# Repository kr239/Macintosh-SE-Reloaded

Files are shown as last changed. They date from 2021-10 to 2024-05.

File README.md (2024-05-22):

# Macintosh SE Reloaded

Finished Logic Board
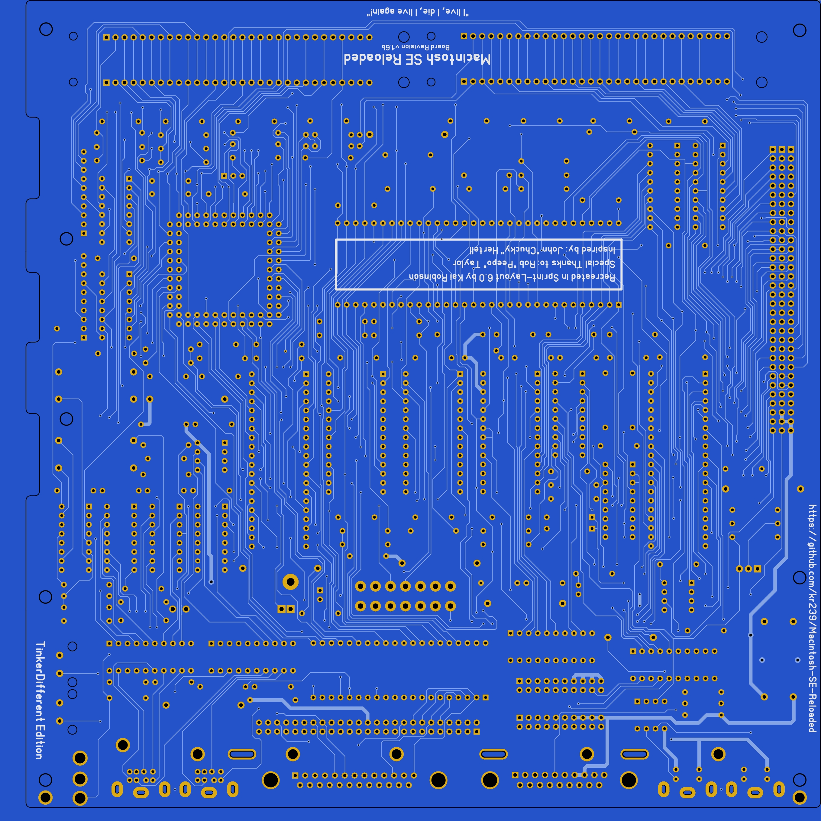
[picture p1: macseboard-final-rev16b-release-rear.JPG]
Finished Logic Board - Bottom


**Latest version, v1.6 adds an A17 address pin next to **U2E**, a 74F257 to allow for potential ROM upgrades as the standard ROM sockets only allow A0 to A16 address lines.**

So many classic macs, starting with the SE, have died because of Apple's short sighted decision to add a battery to the board. This inevitably leaks and causes a horrific amount of damage. Luckily - most of the custom chips survive even this, so I decided to make a near 1:1 reproduction of the board, using Sprint Layout v6.0

Project inspired by Rob 'Peepo' Taylors work on the A500++ and the SixtyClone PCB's, which in turn were inspired by John 'Chucky' Hertell. 

Please note - this project is licensed under CC-BY-NC-SA - it is NOT for commercial use.

Only two vendors are licensed for commercial production. Maceffects (US) and Recapamac (Australia). 

If you wish to purchase a single, ready made board, I recommend purchasing from them direct. 

https://maceffects.com/products/macintosh-se-reloaded-logic-board

https://recapamac.com.au/shop/

# List of parts to save from the Macintosh SE Board

* **SIMM Sockets** - If you can get some from here: https://www.peconnectors.com/sockets-pga-cpu-and-memory/hws9229/ then do so! 
 
  Re-using and cleaning up your old ones involves desoldering. These need a lot of heat as there are a lot of connections to the ground plane. Pre-heat the joints, maybe add a dab of proper Kester 63/37 eutectic LEADED solder (none of that RoHS crap), flood with flux. 
* **PDS Socket** - Amphenol/AMP/AVX DIN-41612 3-row, 96-pin connector (Style-C) - Available new, but still worth reclaiming as sifting through the minute variations of parts is an arse...
* **DB19 Connector** - Almost NLA, only really available as NoS or Reclaimed. These are a bastard to get out cause the lugs are soldered. I found that pre-heating the joint first, filled with flux, then pressing hard into the pad with the desoldering gun, waiting til you see the solder go molten, you can often schlorp out the majority of the solder and then tidy up with wick afterwards. 
 
  NoS ones available from https://www.exxoshost.co.uk/atari/store2/ - search for **DB19F ASCI PCB RA POST**
* **Main 14-pin Molex** - Molex P/N 39-28-1143 - Still available new - costs less than £2. Get a new one. 
* **Inductors** - probably easy enough to get new ones, but ehhh, they don't really break, and they fit fine. Reuse the big ones - buy new small axial ones.  
* **Passives** - **REPLACE ALL** - use high tolerance metal film resistors & nichicon or panasonic electrolytics. Maybe try and save the PLCC Socket if you can. remove it cleanly - sometimes the pins pull out but they can be put back in if you're careful. 
* **AM26LS30's** - NLA, only available as NoS or Reclaimed
* **AM26LS32's** - Available new, but still worth reclaiming
* **MC3488A** - NLA - replace with Texas Instruments SN75150
* **Rockwell 338-6523** - This is identical to the 65C22N VIA, still available new
* **RTC Chip** - Custom Chip - this has been reverse engineered, see project here: https://github.com/pgreenland/attinyrtcmodule
* **ADB Chip** - Apple branded PIC16CR54 - this has been reverse engineered for the PIC16F88 by Tashtari: https://github.com/lampmerchant/macseadb88
* **GLU Chip** - Apple branded HAL16L8 - this has been reverse engineered for both GAL16V8 and discrete logic!
* **BBU Chip** - Custom Chip
* **SCC Chip** - Standard 85C30 Serial Communications controller - **NO LONGER AVAILABLE NEW AS OF 2024-06-01, officially discontinued by ZiLOG**
* **NCR5830/AM58C30 SCSI Chip** - NLA, only available as NoS or Reclaimed from UTSource
* **IWM/SWIM Floppy Chip** - Custom Chip - available NoS from UTSource
* **Hi & Lo ROM Chips** - Toshiba TC531000CP MASK ROM's - Reclaim & reuse, but these are the same pinout as 27C512, but adds A16 in place of VPP pin - you can use 27C010's on an adapter - doug brown made a similar setup with a built in ROM disk for the Mac Plus. 
* **74LS245** - Available new, but still worth reclaiming - replace with CY74FCT245ATPC or CD74FCT245E
* **74F257** - Available new, but still worth reclaiming - replace with CD74ACT257E

A full BOM is now available.

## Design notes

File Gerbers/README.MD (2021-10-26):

Download and use the .zip archive for services such as PCBWay or JLCPCB.

Layer sequence is: 

**MacintoshSE_copper_top.gbr**

**MacintoshSE_copper_inner1.gbr**

**MacintoshSE_copper_inner2.gbr**

**MacintoshSE_copper_bottom.gbr**

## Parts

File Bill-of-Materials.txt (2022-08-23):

* Partlist from file: MacintoshSE.lay6" / 12/06/2022 19:05:44
*
* Name	Value
*

C1	100nF
C2	100nF
C3	100nF
C4	33uF 16v
C5	100nF
C6	100nF
C7	100nF
C8	100nF
C9	100nF
C10	100nF
C11	33uF 16v
C12	100nF
C13	33uF 16v
C15	100nF
C16	33uF 16v
C17	100nF
C18	33pF
C19	10pF
C20	100nF
C21	100nF
C22	100nF
C23	100nF
C24	100nF
C25	100nF
C26	33uF 16v
C27	100nF
C28	100nF
C29	100nF
C30	100nF
C31	100nF
C32	33uF 16v
C33	100nF
C34	33uF 16v
C35	100nF
C36	1uF 16v
C37	33uF 16v
C38	33uF 16v
C39	100nF
C40	68pF
C41	100nF
C42	100nF
C43	100nF
C44	100nF
C45	100nF
C46	100nF
C47	100nF
C48	100nF
C49	100nF
C50	100nF
C51	100nF
C52	100nF
C53	100nF
C54	100nF
C55	100nF
C56	100nF
C57	100nF
C58	100nF
C59	100nF
C60	100nF
C61	100nF
C62	33uF 16v
C63	100nF
C64	100nF
C65	100nF
C66	100nF
C67	-= DO NOT POPULATE! =-
CR1	1N4150
CR2	1N4150
CR3	1N4150
J1	EAR			Kobiconn 161-3520-EX
J2	SERIAL			TE 5749268-1
J3	SERIAL			TE 5749268-1
J4	EXT SCSI		Amphenol L77SDB25S1ACH4R
J5	INT SCSI		Molex 87834-5019
J6	EXT FLOPPY		NLA - Reuse
J7	UPPER DRIVE		Molex 90130-1320
J8	LOWER DRIVE		Molex 90130-1320
J9	ADB			TE 5749181-1
J10	ADB			TE 5749181-1
J11	Speaker Molex KK 171856-1002
J12	MAIN			Molex 39-28-1143
J13	PDS			Harting 09032966825 
J14	SIMM			PE Connectors HWS9229
J15	SIMM			PE Connectors HWS9229
J16	1x3 HEADER
L1	27uH
L2	33uH
L3	33uH
L4	Ferrite Bead
Q1	2N3904
R1	10k
R2	10
R3	47
R4	47
R5	560k
R6	10
R7	10
R8	1.2k
R9	47
R10	47
R11	1k
R12	150
R13	1k
R14	470
R15	1k
R16	3.3k			
R17	10k
R18	1k
R19	10
R20	75
R21	3.3k
R22	47
R23	47
R24	47
R25	560
R26	3.3k
R27	3.3k
R28	47
R29	47
R30	47
R31	10k
R32A	47
R33A	47
R34	10k
R35	150
R36	150
R37	39
R38	39
R39A	47
R40A	47
R41	3.3k
R42	39
R43	3.3k
R44	3.3k
R45	3.3k
R46	3.3k
R47	3.3k
R48	3.3k
RP1	39			Bourns 4610X-102-390LF
RP2	39			Bourns 4610X-102-390LF
U1C	SND        Apple 343-0045-B
U2B	FILTER			Bourns 4120R-601-250/201
U2C	26LS30			NLA - get New-old-Stock
U2E	74ACT257
U2F	74ACT257
U3C	26LS32			TI AM26LS32ACN
U4B	FILTER			Bourns 4120R-601-250/201
U4C	26LS32
U4D	MC3488A	/ SN75150P	RS-232 Interface IC - Dual Line Driver		
U4E	BBU
U5D	85C30 SCC		ZiLOG Z85C3010PSG
U6B	5830 SCSI
U6D	ROM HIGH
U7D	ROM LOW
U7E	MC68000
U8B	FILTER			Bourns 4120R-601-250/201
U8D	SWIM    Apple 344-0062-A
U9D	GLU			Apple 342-0538-A
U10C	ADB
U10D	16 Mhz Clock		
U11A	ADB FILTER		HALO LD11-0246FLF (24uH Common Mode 1:1:1:1 Choke)
U11B	FILTER			Bourns 4120R-601-250/201
U11C	RTC      Apple 344-0042-B
U11D	Rockwell 338-6523 or WDC65C22N
U11F	74FCT245
U12F	74FCT245
Y1	IQD LFXTAL002996Bulk - 32.768 KHz
SW1   ALPS SKHCBFA010
SW2   ALPS SKHCBFA010

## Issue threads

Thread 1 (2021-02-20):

Board trace issues

drew0986, 2021-02-20:
I looked over the Baird pics and I think I identified a few places where the was board transcription errors form the original pictures to a new board layout. I know you have already corrected some of these errors, but I thought that a second set of eyes on some possible trace inconsistencies may help. If the information I provide is incorrect please disregard, and I apologize for any errors that I make. I’m truly just trying to be helpful and a big fan of this project and what you are trying to accomplish. Truly amazing my goodman.
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

kr239, 2021-02-21:
Hi there - that was v1.2 - i've just uploaded the v1.4e board views - the scans are a little offset from the sprint layout, mostly because the board was twisted and even with weight, didn't scan totally flat. I've corrected a lot of the errors already, but please have a look through the 1.4's to see if any issues still remain. Many Thanks, Kai

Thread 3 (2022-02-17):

BOM part for floppy header is incorrect

rezafouladian, 2022-02-17:
In the BOM, the part number for the internal floppy headers seems to be incorrect. Molex 87831-5920 is a 2mm pitch header with a pin missing, but the floppy connector uses a 2.54mm pitch header with no keying pin missing.

https://github.com/kr239/Macintosh-SE-Reloaded/blob/40224c69977c1934ab2df64152922805e2ee3ff2/Bill-of-Materials.txt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

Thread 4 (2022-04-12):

SW1 and SW2 are missing in the BOM

MastaTabs, 2022-04-12:
Well, they are pushbuttons, but which size are they ?

MastaTabs, 2022-04-19:
I have researched the topic for a bit but haven't found an exact equivalent. All I know so far is that the body width is 12x12mm and the pin pitch is 5mm.

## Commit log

2020-08-10 Create Bill-of-Materials
2020-08-10 Update Bill-of-Materials.txt
    Changed filetype extension
2021-06-03 Update Bill-of-Materials.txt
    Swap C5 value to 100nF
2021-10-26 Add files via upload
    Zipped archive of Gerber files for easy deployment at JLCPCB.
2021-10-26 Add files via upload
    Sprint Layout file for v1.5-RELEASE board
2022-04-11 Update Bill-of-Materials.txt
    Changed Molex P/N
2022-08-23 Update Bill-of-Materials.txt
    Amend SCSI
2024-02-27 Delete Gerbers/Macintosh-SE-Reloaded-v1.5a-release.zip
    Inbound new version
2024-02-27 Update README.md
    Addition of A18 pin
2024-05-22 Add files via upload
    Silkscreen edit for A17 tap for ROM
